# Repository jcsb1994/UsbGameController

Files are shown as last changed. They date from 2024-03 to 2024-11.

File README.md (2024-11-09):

# UsbGameController

This repo contains source code and CAD files (step 3D files and PCB gerber files) for assembling a 3D-printed HID joystick/keyboard based on the Arduino framework.

- [UsbGameController](#usbgamecontroller)
  - [Hardware setup](#hardware-setup)
    - [Materials](#materials)
  - [Software setup](#software-setup)
    - [Requirements](#requirements)
    - [Build](#build)

## Hardware setup

The gerber files are provided so that they can be sent to any PCB manufacture as-is.

**Note:** The PCB was made with Altium Circuit Maker Pro, which is being deprecated. The CircuitMaker project files are not in the repo. The PCB will need to be designed again in KiCad.

The step files are provided so that they can be exported as STL and sliced and 3D-printed, or edited on any CAD.

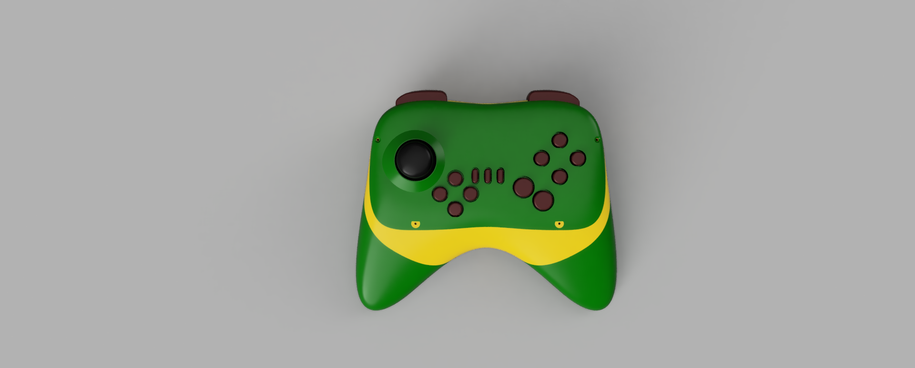
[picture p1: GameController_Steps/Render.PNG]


### Materials
The BOM is available at `GameController_PCB\BOM.xlsx`. Note that resistor values are not specified, use standard pull-up and led resistance values.

The main PCB mounts a 24-pin Arduino micro, which is based on the Atmega32u4, as it supports USB HID.

## Software setup

### Requirements

- VS Code
- PlatformIO extension
  
### Build
The project was built with PlatformIO on VS Code. 

to build, open the subfolder `GameController_Firmware` and build the project there using the PIO API. Simply plug in the Arduino micro to flash the program.

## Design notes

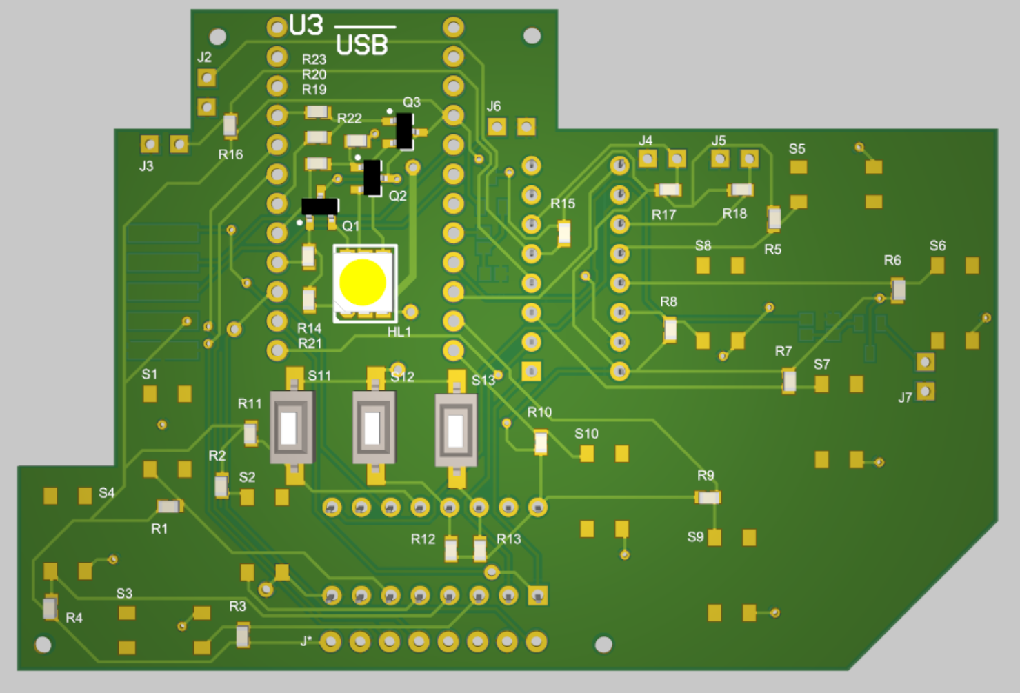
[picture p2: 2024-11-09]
GameController_PCB/PCB_3D.png

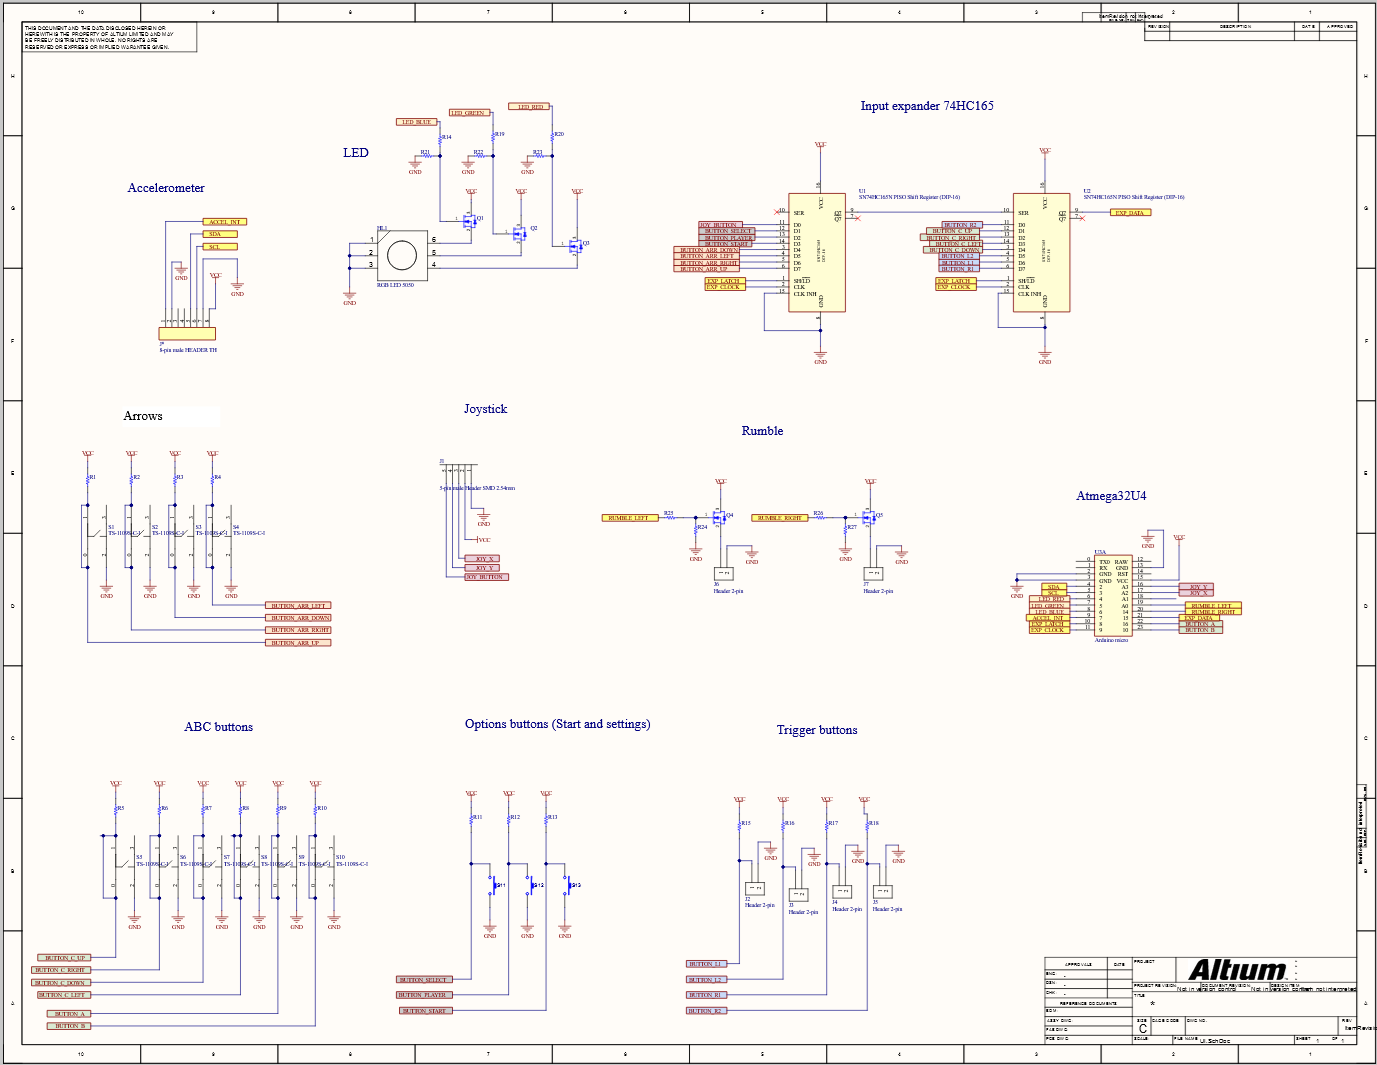
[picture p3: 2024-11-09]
GameController_PCB/SCH.png

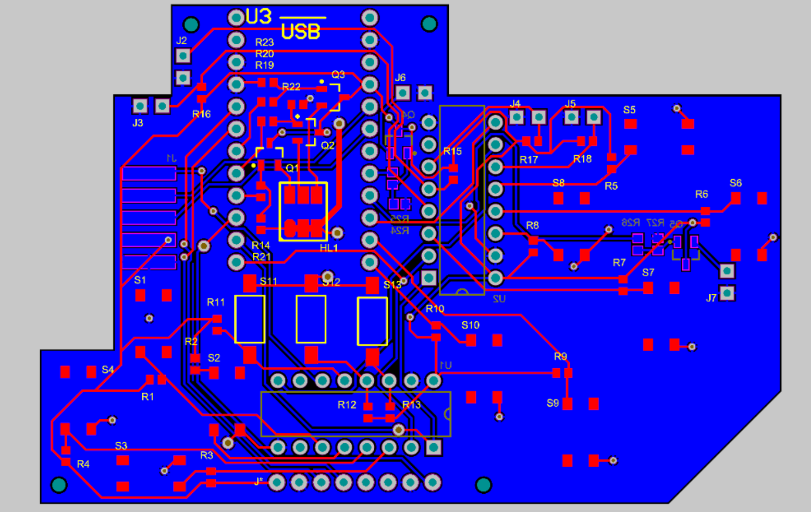
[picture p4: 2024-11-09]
GameController_PCB/PCB.png

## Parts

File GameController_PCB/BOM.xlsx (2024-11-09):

RGB LED 5050 (https://octopart.com/2343-adafruit+industries-54178364)
$0.17
LED APA102 5050 RGB
HL1
1
5-pin male Header SMD 2.54mm (https://octopart.com/fan3100csx-onsemi-84324989)
$0.30
For side-mounting 5-pin modules
J1
1
Header 2-pin (https://octopart.com/280370-2-te+connectivity-40018729)
$0.14
AMPMODU Mod II Series, 2.54mm Pitch 2Way1 Row Straight PCB Header, Solder Term, 3A
J2J3J4J5J6J7
6
8-pin male HEADER TH (https://octopart.com/68000-206hlf-amphenol+communications+solutions-126518164)
$0.27
2.54 mm pitch header pin holes
J*
1
ON Semiconductor BSS138LT1G (https://octopart.com/bss138lt1g-onsemi-5035)
$0.03
MOSFET, Power; N-Ch; VDSS 50VDC; RDS(ON) 3.5 Ohms; ID 200mA; SOT-23 (TO-236); PD 225mW
Q1Q2Q3Q4Q5
5
TE Connectivity CRGCQ0603F10K (https://octopart.com/crg1206zr-te+connectivity-19955218)
N/A
Res General Purpose Thick Film 0603 10k Ohm 1% 1/10W ±100ppm/°C Molded Paper T/R
R1R2R3R4R5R6R7R8R9R10R11R12R13R14R15R16R17R18R19R20R21R22R23R24R25R26R27
27
TS-1109S-C-I (https://octopart.com/ts-1109s-c-i-xkb+connectivity-120082637)
$0.02
https://www.x-on.com.au/mpn/xkb/ts1109sci
S1S2S3S4S5S6S7S8S9S10
10
C&K Components PTS636SM43JSMTRLFS (https://octopart.com/tl1015af160qg-e-switch-1057779)
$0.47
Switch Tactile Top Actuated SPST N.O. 12V 50mA Black Actuator Surface Mount T/R
S11S12S13
3
SN74HC165N PISO Shift Register (DIP-16) (https://octopart.com/mc74hc595afl1-onsemi-3955613)
$0.10
Shift Register Single 8 Bit Serial Parallel To Serial 16 Pin Plastic DIP Tube
U1U2
2
Arduino micro (https://octopart.com/a000053-arduino-26601537)
$21.91
Arduino Pro Micro 24-pin
U3
1

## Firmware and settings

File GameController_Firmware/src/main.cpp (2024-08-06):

/*! Created on Wed Nov 29 2023
    \author jcsb@pixmob.com
    \copyright jcsb@pixmob.com
    ~~~~~~~~~~~~~~~~~~~~~~~~~~~~~~~~~~~~~~~~~~~~~~~~~~~~~~~
    \brief USB game controller firmware
    
*/

#include <Arduino.h>
// project modules
#include "bsp.h"
#include "74hc165.h"
#include "keyJoystick.h"
// submodules
// #include <Adafruit_MPU6050.h>
#include "tact.h"


// #define DEBUG_MAINlR                                                                                                                                                                                                               lRrrrrrrrrrrrrrrrrrrrrrrrrrrrrrrrrrrrrrrrrrrrrrrrrrrrrrrrrrrrrrrrrrrrrrrrrrrrrrrrrrrrrrrrrrrrrrrrrrrrrrrrrrrrrrrrrrrrrrrrrrrrrrrrrrrrrrrrrrrrrrrrrrrrrrrrrrrrrrrrrrrrrrrrrrrrrrrrrrrrrrrrrrrrrrrrr
// WARNING: Do not put looped msgs will prevent flashing
// (Short top right pins 2 and 3 to reset in bootloader)

#ifndef DEBUG_MAIN
#define debugf_init()
#define debugf(msg)
#else
#define debugf_init() Serial.begin(9600);
#define debugf(msg) Serial.println(msg)
#endif

// Accelerometer
// =======================
// mpu6050 mpu;
// Adafruit_MPU6050 mpu;


// Buttons
// =======================
#define TACT_POLL_FREQ_HZ (100)
#define TACT_SR_LOGIC 0 // Shift register button logic
#define TACT_SHIFT_REG_NB 2
#define TACT_GPIO_LOGIC 0 // Buttons on GPIOs logic

#define IO_TACT_INIT(pin) tact(PIN_BTN_##pin, ioRead, TACT_POLL_FREQ_HZ, TACT_GPIO_LOGIC)
#define SHIFT_TACT_INIT(pin) tact(SHIFT_BTN_##pin, shiftRead, TACT_POLL_FREQ_HZ, TACT_SR_LOGIC)

shift165 shiftin = shift165(PIN_SHIFT_DATA, PIN_SHIFT_CLOCK, PIN_SHIFT_LATCH, TACT_SHIFT_REG_NB);

int shiftRead(int bit) { return shiftin.read(bit); }
inline int ioRead(int io) { return digitalRead((uint8_t)io); }

tact buttons[] = {
  // Buttons connected to MCU IOs
  IO_TACT_INIT(A),
  IO_TACT_INIT(B),
  // Buttons connected to shift register pins
  SHIFT_TACT_INIT(L),
  SHIFT_TACT_INIT(L2),
  SHIFT_TACT_INIT(R),
  SHIFT_TACT_INIT(R2),
  SHIFT_TACT_INIT(START),
  SHIFT_TACT_INIT(SELECT),
  SHIFT_TACT_INIT(C_UP),
  SHIFT_TACT_INIT(C_DOWN),
  SHIFT_TACT_INIT(C_LEFT),
  SHIFT_TACT_INIT(C_RIGHT),
  SHIFT_TACT_INIT(ARR_UP),
  SHIFT_TACT_INIT(ARR_DOWN),
  SHIFT_TACT_INIT(ARR_LEFT),
  SHIFT_TACT_INIT(ARR_RIGHT),
  // Put config buttons last
  SHIFT_TACT_INIT(PLAYER),
};

const uint8_t nb_buttons = sizeof(buttons)/sizeof(tact);
const uint8_t nb_ioButtons = 2;
const uint8_t nb_configButtons = 1;


// Joystick / keyboard
// =======================

/*! \brief This table maps to the Joystick button indexes on the HID device on the PC
  It also maps to the order of the local array buttons[] */
typedef enum {
BTN_IDX_A,
BTN_IDX_B,  

BTN_IDX_L,
BTN_IDX_L2,
BTN_IDX_R,
BTN_IDX_R2,

BTN_IDX_START,
BTN_IDX_SELECT,

BTN_IDX_C_UP,
BTN_IDX_C_DOWN,
BTN_IDX_C_LEFT,
BTN_IDX_C_RIGHT,

BTN_IDX_ARR_UP,
BTN_IDX_ARR_DOWN,
BTN_IDX_ARR_LEFT,
BTN_IDX_ARR_RIGHT,

// Local buttons (not transmitted via HID, configs the controller)
BTN_IDX_PLAYER,
} button_idx_t;

keyjoy_button_t button_keys[] = {
  {.id = BTN_IDX_A,           .ascii = ' '},
  {.id = BTN_IDX_B,           .ascii = KEY_KP_ENTER},
  {.id = BTN_IDX_L,           .ascii = 'l'},
  {.id = BTN_IDX_L2,          .ascii = 'L'},
  {.id = BTN_IDX_R,           .ascii = 'r'},
  {.id = BTN_IDX_R2,          .ascii = 'R'},
  {.id = BTN_IDX_START,       .ascii = KEY_ESC},
  {.id = BTN_IDX_SELECT,      .ascii = 'p'},
  {.id = BTN_IDX_ARR_UP,      .ascii = KEY_UP_ARROW},
  {.id = BTN_IDX_ARR_DOWN,    .ascii = KEY_RIGHT_ARROW},
  {.id = BTN_IDX_ARR_LEFT,    .ascii = KEY_LEFT_ARROW},
  {.id = BTN_IDX_ARR_RIGHT,   .ascii = KEY_DOWN_ARROW},
  {.id = BTN_IDX_C_UP,        .ascii = 'r'},
  {.id = BTN_IDX_C_DOWN,      .ascii = 'E'},
  {.id = BTN_IDX_C_LEFT,      .ascii = 'm'},
  {.id = BTN_IDX_C_RIGHT,     .ascii = KEY_TAB},

};

keyJoystick Keyjoy = keyJoystick(button_keys, PIN_JOY_X, PIN_JOY_Y);


// Main
// =======================

void setup() {
  debugf_init();
  debugf("USB Gaming!");

  // Accelerometer
  // mpu.init();
  // wire.begin()
  // mpu.begin();

  // Buttons
  for (uint8_t i = 0; i < nb_buttons; i++) {
    buttons[i].setDebouncePeriod(30);
  }
  for (uint8_t i = 0; i < nb_ioButtons; i++) {
    pinMode(buttons[i].getPin(), INPUT);
  }

  // Analog Joystick
  pinMode(PIN_JOY_X, INPUT);
  pinMode(PIN_JOY_Y, INPUT);

  // HID Joystick
  #ifndef DEBUG_MAIN
  Keyjoy.begin();
  #endif
  
  // Leds
  pinMode(PIN_LED_R, OUTPUT);
  pinMode(PIN_LED_G, OUTPUT);
  pinMode(PIN_LED_B, OUTPUT);

  shiftin.init();
}

int iButt = 0; // Must be global, used in lambdas

// Color pulse
uint8_t color_idx = 0;
int8_t intensity = 0;
int8_t dir = 1;
uint8_t max_col_idx = 3;
uint8_t rgb[4][3] = {
  {0, 0, 0},
  {255, 0, 0},
  {0, 255, 0},
  {255, 255, 0}
};

void color_step()
{
  intensity+=dir;
  if (intensity >= 100 || !intensity) { dir = -dir; }
  float r = (rgb[color_idx][0] * intensity) / 100;
  float g = (rgb[color_idx][1] * intensity) / 100;
  float b = (rgb[color_idx][2] * intensity) / 100;
  analogWrite(PIN_LED_R, r);
  analogWrite(PIN_LED_G, g);
  analogWrite(PIN_LED_B, b);
}


void loop() {
  static unsigned long last_poll = 0;
  static unsigned int millisec_between_polls = 1000 / TACT_POLL_FREQ_HZ;

  if (millis() - last_poll >= millisec_between_polls) {
 
    color_step();
  
    Keyjoy.read_stick();

    shiftin.capture();
    for (iButt = 0; iButt < (nb_buttons-nb_configButtons); iButt++) {
      #ifndef DEBUG_MAIN
      
      buttons[iButt].poll([] { Keyjoy.press(iButt);  },
                      [] { Keyjoy.release(iButt); },
                      0,
                      [] { Keyjoy.release(iButt); });
      
      #else
      buttons[iButt].poll([] {  debugf("Idx: " + String(iButt) + " Pin: " +  String(buttons[iButt].getPin()));  },
                      [] { debugf((char)button_keys[iButt].ascii); },
                      [] {  });
      #endif
    }


    // Last button in the index is a special button, not a HID button
    buttons[nb_buttons-1].poll([] { debugf("CONF: " + String(iButt) + " Pin: " +  String(buttons[iButt].getPin()));  },
                    [] { color_idx++; if(color_idx > max_col_idx) {color_idx = 0;} },
                    [] {
                      digitalWrite(PIN_LED_B, HIGH);
                      Keyjoy.begin();
                      digitalWrite(PIN_LED_B, LOW);
                    });
                          


    last_poll += millisec_between_polls;

    #ifndef DEBUG_MAIN
    Keyjoy.update();
    #endif
  }

  // poll buttons, joystick
  // read accelerometer if ON
  // leds if buttons pressed
  // rumble when accelerometer moves fast

  // switch for rumble, accelerometer
  // transistors for rumble 2
}

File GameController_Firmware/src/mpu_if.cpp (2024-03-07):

// #include <Arduino.h>

// void mpu_if::init(mpu_if::mpu_sensitivity sensi)
// {
//   Wire.begin();

//   _writeI2cReg(0x6B, 0); // reset chip
//   _writeI2cReg(0x1C, (uint8_t)sensi); // ACCEL_CONFIG
//   _writeI2cReg(0x1B, 0x10); //GYRO_CONFIG reg (1000deg/s full scale)

//   mpu.setHighPassFilter(MPU6050_HIGHPASS_0_63_HZ);
//   mpu.setMotionDetectionThreshold(1);
//   mpu.setMotionDetectionDuration(20);
//   mpu.setInterruptPinLatch(true);	// Keep it latched.  Will turn off when reinitialized.
//   mpu.setInterruptPinPolarity(true);
//   mpu.setMotionInterrupt(true);
// }

// mpu_if::imuReadings mpu_if::getValues()
// {
//   // return if no data ready
//   mpu_if::imuReadings rc;

//   Wire.beginTransmission(_i2c_addr);
//   Wire.write(0x3B); // Start with register 0x3B (ACCEL_XOUT_H)
//   Wire.endTransmission(false);
//   Wire.requestFrom(_i2c_addr, 6, true); // Read 6 registers total, each axis value is stored in 2 registers
//   //For a range of +-2g, we need to divide the raw values by 16384, according to the datasheet
//   for (uint8_t i = 0; i < 3; i++)
//   {
//     rc.acceleration[i] = _getAccVal();
//   }

//   // Calculating Roll and Pitch from the accelerometer data
//   rc.xAccAngle = (atan(rc.acceleration[1] / sqrt(pow(rc.acceleration[0], 2)
//    + pow(rc.acceleration[2], 2))) * 180 / PI) - 0.58; // AccErrorX ~(0.58) See the calculate_IMU_error()custom function for more details
//   rc.yAccAngle = (atan(-1 * rc.acceleration[0] / sqrt(pow(rc.acceleration[1], 2)
//    + pow(rc.acceleration[2], 2))) * 180 / PI) + 1.58; // AccErrorY ~(-1.58)

//   // === Read gyroscope data === //
//   float elapsedTime = _getElapsedMs() / 1000;
//   _lastReadTimestamp = millis();

//   _requestReadI2c(0x43, 6); // accel data

//   for (uint8_t i = 0; i < 3; i++)
//   {
//     rc.gyro[i] = _getGyroVal();
//   }

//   // Correct the outputs with the calculated error values
//   rc.gyro[0] += 0.56; // GyroErrorX ~(-0.56)
//   rc.gyro[1] -= 2; // GyroErrorY ~(2)
//   rc.gyro[2] += 0.79; // GyroErrorZ ~ (-0.8)

//   // Currently the raw values are in degrees per seconds, deg/s, so we need to multiply by sendonds (s) to get the angle in degrees
//   float gyroAngleX = gyroAngleX + rc.gyro[0] * elapsedTime; // deg/s * s = deg
//   float gyroAngleY = gyroAngleY + rc.gyro[1] * elapsedTime;
//   float yaw =  yaw + rc.gyro[2] * elapsedTime;

//   // Complementary filter - combine acceleromter and gyro angle values
//   float roll = 0.96 * gyroAngleX + 0.04 * rc.xAccAngle;
//   float pitch = 0.96 * gyroAngleY + 0.04 * rc.yAccAngle;

//   // Print the values on the serial monitor
//   Serial.print(roll);
//   Serial.print("/");
//   Serial.print(pitch);
//   Serial.print("/");
//   Serial.println(yaw);

//   return rc;
// }

// void mpu_if::_requestReadI2c(uint8_t reg, uint8_t size)
// {
//   Wire.beginTransmission(_i2c_addr);
//   Wire.write(reg); // Start with register 0x3B (ACCEL_XOUT_H)
//   Wire.endTransmission(false);
//   Wire.requestFrom(_i2c_addr, size, true);
// }

// void mpu_if::_writeI2cReg(uint8_t reg, uint8_t data)
// {
//   Wire.beginTransmission(_i2c_addr);
//   Wire.write(reg);
//   Wire.write(data);
//   Wire.endTransmission(true);
// }

// uint32_t mpu_if::_getElapsedMs()
// {
//     uint32_t now = millis();
//     if (now < _lastReadTimestamp) {
//         return now + (UINT32_MAX - _lastReadTimestamp);
//     } else {
//         return now - _lastReadTimestamp;
//     }
// }

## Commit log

2023-11-24 Proto-app with button functionality
2023-11-30 Buttons IO and Shift work
2023-12-24 Petit cleanup de Noel
2024-03-07 shift reg buttons not working
    [main.cpp, mpu_if.cpp]
2024-03-15 Colors and buttons work
2024-11-08 Added gerbers
    Missing resistors in series for the RGB led
    [PCB.GBL, PCB.GBO, PCB.GBS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]
2024-11-09 Added BOM and References to PCB project
    In order to re-design the PCB, one will need to refer to the provided step file for component placements to match the controller casing
    [BOM.xlsx]
